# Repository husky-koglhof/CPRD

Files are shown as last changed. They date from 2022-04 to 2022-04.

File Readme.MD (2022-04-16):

# Cardio pulmonary resuscitation Dummy (CPRD)

## CPRD ist eine Simulations Hard- bzw. Software welche dafür eingesetzt werden kann um folgende Themen zu simulieren

- Blutkreislauf
  Es kann ein Relais für einen konfigurierbaren Zeitraum ein- bzw. ausgeschaltet werden.
- Beatmung
  Es kann ein Relais für einen konfigurierbaren Zeitraum ein- bzw. ausgeschaltet werden.
- Temperatur
  Es kann ein Relais für einen konfigurierbaren Zeitraum eingeschaltet werden.
- Puls
  Der angeschlossene Servo kann so konfiguriert werden, um einen Puls nachzuahmen.
- ✨Magic ✨

## Merkmale

Die globalen Parameter werden hier kurz beschrieben:

* Die WLAN SSID ist ```CPRD```
* Das Standard WLAN Passwort ist ```CPRD_password```
* Settings Authentifizierung
  Benutzer: ```admin```
  Passwort: ```admin```
* Update (OTA) Authentifizierung
  Benutzer: ```admin```
  Passwort: ```tobedefined```
* Buttons

  * Speichern -> Speichern der Parameter im EEPROM
  * Start -> Starte mit den aktuell sichtbaren Parametern
  * Abbrechen -> Veränderungen rückgängig machen (nur solange nicht gespeichert wurde)
* Parameter (x)

  * Jeglicher Parameter kann mittels dem Schieberegler konfiguriert werden. Der aktuelle Wert wird im Text angezeigt.

##### Blutkreislauf

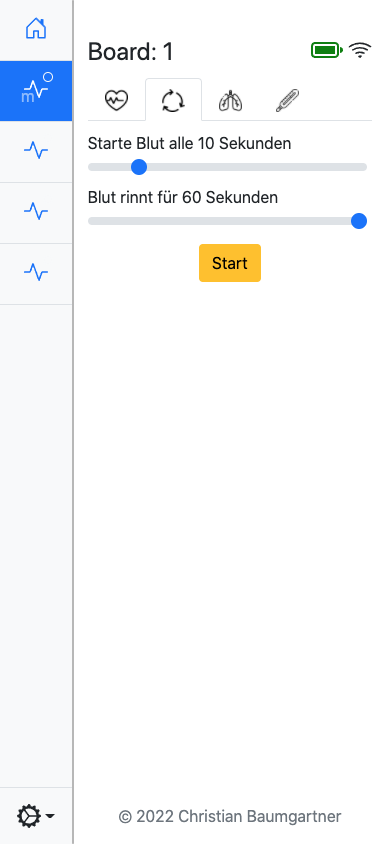
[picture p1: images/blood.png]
Blood


* Starte Blut alle x Sekunden
* Blut rinnt für x Sekunden

##### Beatmung (Lunge)

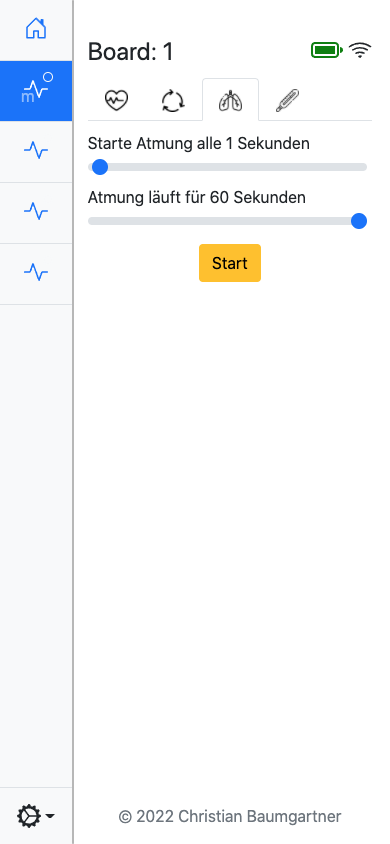
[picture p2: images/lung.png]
Lung


* Starte Atmung alle x Sekunden
* Atmung läuft für x Sekunden

##### Körpertemperatur (Fieber)

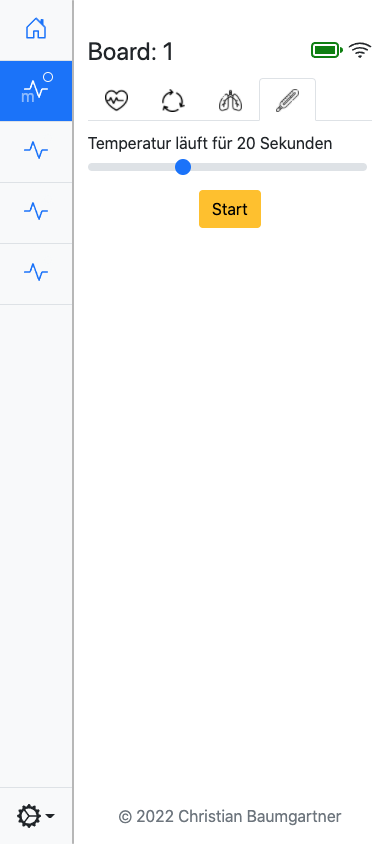
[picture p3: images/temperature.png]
Temperature


* Temperatur läuft für x Sekunden

## Anzeigen

### Zuhause (Home)

Die Hauptansicht zeigt immer alle derzeit verwendeten Boards an.Das derzeit aktive "Master Board" ist zusätzlich mit einem "m" markiert.Sollte ein Board einen zu geringen Batteriestatus haben, wird dies am jeweiligen Board im Menü angezeigt.

* Batterie < 90% = GELB
* Batterie < 80% = ROT

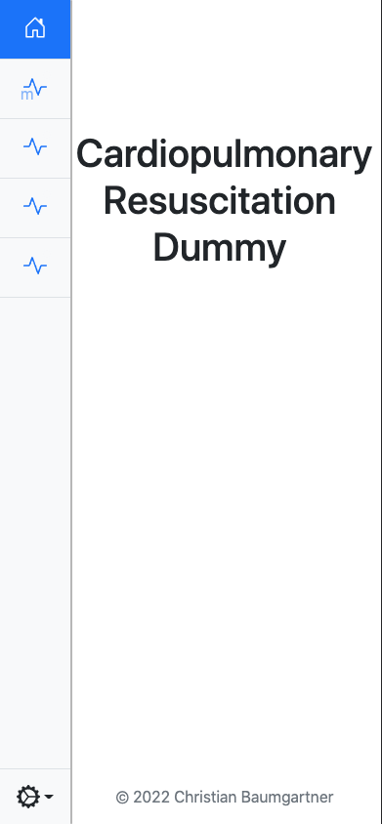
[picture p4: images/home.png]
Home


Sollten Boards nicht mehr aktiv sein (z.B. ausser Reichweite, Batterie leer), werden diese
im linken Baum als "ausgegraut" dargestellt:

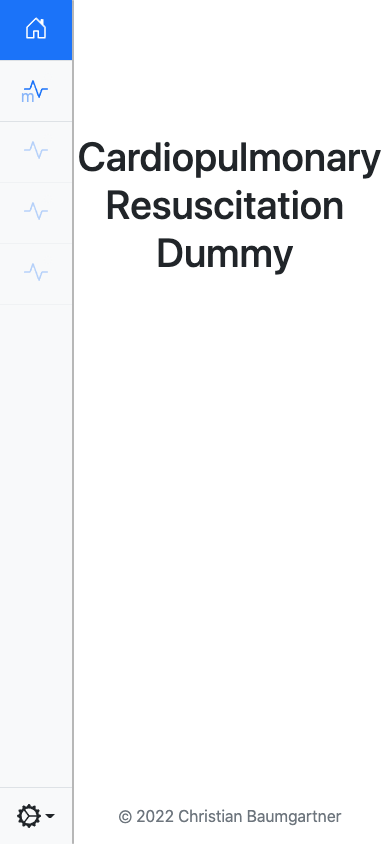
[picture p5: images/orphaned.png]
Orphaned


### Menü

Über das Menü links unten können folgende Seiten geöffnet werden. Dies funktioniert nur bei ausgewähltem Board, da diese Seiten Echtzeitdaten darstellen.

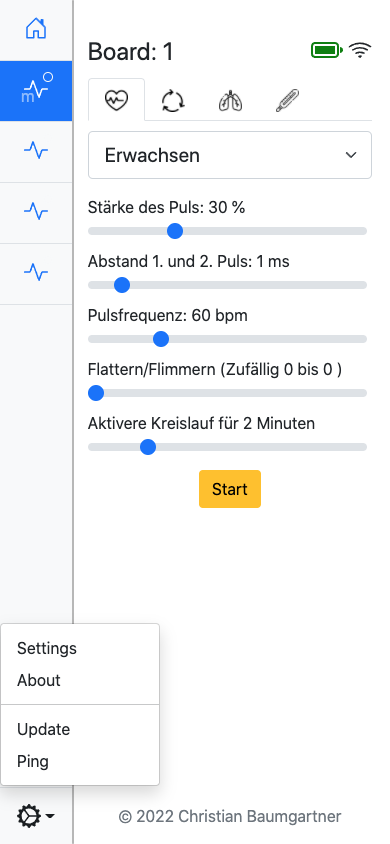
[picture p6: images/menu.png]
Menu


##### Settings

In dieser Seite können folgende Parameter konfiguriert werden:

* Board ID
  Diese sollte nur verändert werden, wenn es zu einem Konflikt mit einem anderen Board kommt, welche die gleiche ID verwendet.
* SSID
  Es ist möglich eine eigene WLAN SSID zu vergeben, z.B. um mehrere "Master" gleichzeitig verwenden zu können.

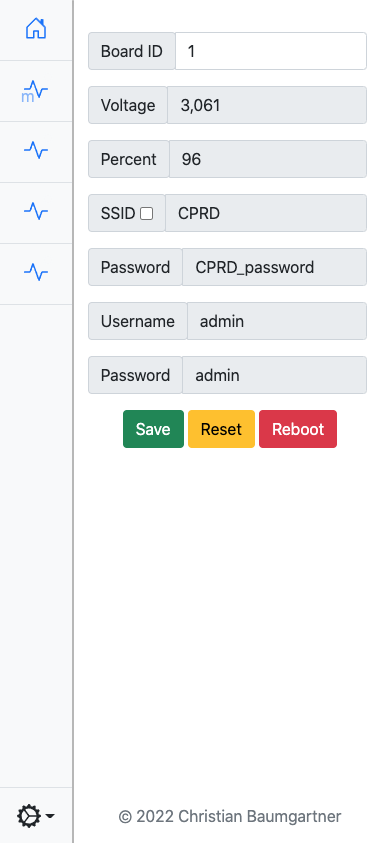
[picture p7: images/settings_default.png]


* Save
  Speichern der Daten im EEPROM
* Reset
  Zurückstellen aller Einstellungen auf den Auslieferungszustand (Board wird neu gestartet)
* Reboot
  Board wird neu gestartet

##### About

Anzeige der aktuellen Versionen bzw. der zusätzlich verwendeten Software.

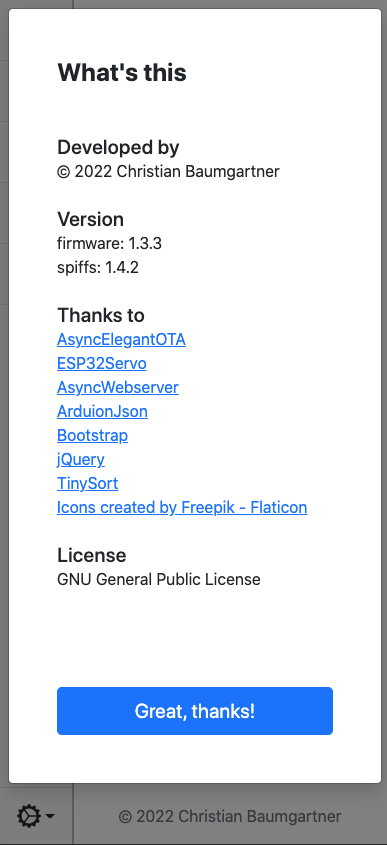
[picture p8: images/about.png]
About


##### Update

Um ein Board aktualisieren zu können, muss es zwingend als "Master" Board aktiv sein. Für die Aktualisierung der Software wird die Auswahl

```Firmware``` und ```firmware.bin``` verwendet.

Für die Aktualisierung der Oberfläche (Webseiten) wird

```Filesystem``` und ```spiffs.bin``` verwendet.

![Update](images/ota.png)

##### Ping

Das derzeit gewählte Board fängt mittels der blauen LED zu blinken an. Somit können die einzelnen Boards aufgefunden werden.

## Anschlüsse

Das System besitzt folgende Anschlüsse (derzeit aktiviert/programmiert):

* USB LadenHierfür kann ein handelsübliches USB Ladegerät verwendet werden.Es darf ausschliesslich nur im abgeschalteten Zustand geladen werden.
  Die LED Anzeige besitzt zwei Zustände
  * Rot: Batterie wird geladen
  * Blau: Batterie ist geladen
* Atmung
  5 Volt Ausgang +/-
* Pumpe
  5 Volt Ausgang +/-
* Temperatur
  5 Volt Ausgang +/-
* Batterie
  Es darf ausschliesslich mit 1S LiPo bzw. 1S LiIon Batterien (z.B. 18650) gearbeitet werden.
  Wenn das Board nicht genutzt wird, sollte die Batterie abgesteckt werden.
* Schalter
  Das Board sollte im nicht genutzten Zustand immer ausgeschaltet sein.

![Pinout](images/board.png)

* Folgende Pins sind derzeit schon auf dem Board vorhanden aber noch nicht aktiv im Einsatz:
  * Relais 4 (Frei)
  * 5 Volt (+/-)
  * 3 Volt (+/-)
  * MISO, MOSI, SS, SCK (z.B. um eine SD Karte anzuschliessen)
  * SDA, SCL (z.B. für externe Sensoren [Temperatur, Luftfeuchte])
  * GPIO1 (TXD)
  * GPIO3 (RXD)

## Development

Die Programmierung erfolgt mittels Visual Studio Code und PlatformIO.

```sh
todo
```

#### Python Webserver

```bash
cd data
gzip -d *.gz
ln -s settings.htm settings
ln -s iframe.htm node
ln -s home.htm home
ln -s config.json update
python3 -m http.server 80
```

#### Bin Dateien erzeugen (OTA Update)

```bash
# spiffs.bin | Filesystem
gzip -9 data/*.js; gzip -9 data/*.css
$HOME/.platformio/penv/bin/platformio run --target buildfs --environment esp32dev
# firmware.bin | Firmware
$HOME/.platformio/penv/bin/platformio run
```

Beim hochladen der spiffs.bin wird die ggf. selbst erzeugte config_new.json entfernt.
Um diese abzuspeichern muss diese (derzeit noch), manuell heruntergeladen werden und die Parameter nach der Aktualisierung per Hand wieder eingestellt werden.
Siehe hierzu [Issue 6](https://github.com/husky-koglhof/CPRD/issues/6)

## Eastereggs

Es sind 3 versteckte Funktionen vorhanden, findest Du sie? 👀️

## Issues

Siehe [Issues](https://github.com/husky-koglhof/CPRD/issues)

## Internals

Für die Kommunikation zwischen den Boards wird [ESP-Now](https://www.espressif.com/en/products/software/esp-now/overview) verwendet.

Beim Start eines Boards wird geprüft ob die SSID (EEPROM) bereits vorhanden ist.

* Wenn ja, wird das Board an diese SSID als Client verbunden
* Wenn nein, wird ein AccessPoint (AP) mit dieser SSID gestartet

Sollte das "Master" Board nicht mehr verfügbar sein (z.B. Stromausfall), kann durch neustart eines beliebigen Boards ein neuer "Master" definiert werden. Die anderen Boards verbinden sich automatisch an diesen als "Client".

Im EEPROM (Adresse 1) sind folgende Daten abgelegt:

```
typedef struct eeprom_struct {
    int boardID;
    bool enableSSID;
    String ssid;
} eeprom_struct;
```

Die Standard Konfiguration liegt unter [/data/config.json](/data/config.json).
Beim verändern und speichern von neuen Daten wird unter ```/data``` eine neue Datei ```config_new.json``` mit den veränderten Daten abgelegt.

Wird über die Settings Seite ein Reset durchgeführt, wird der EEPROM auf den Standard zurückgesetzt und die Datei ```config_new.json``` entfernt.

##### Partitions

Die Partitionstabelle sieht folgendes vor

[Online Editor](https://docs.google.com/spreadsheets/d/1AGFspAP9vPB_HL5ffOyhbxU-URNjrqpOha71I5A4MEI/edit#gid=0)

```bash
# ESP-IDF Partition Table
# Name, Type, SubType, Offset, Size, Flags
nvs,data,nvs,0x9000,20K,
otadata,data,ota,0xe000,8K,
app0,app,ota_0,0x10000,1280K,
app1,app,ota_1,0x150000,1280K,
spiffs0,data,spiffs,0x290000,72K,
spiffs1,data,spiffs,0x2a2000,1400K,
```

```bash
# read out old partition table
python3 $HOME/.platformio/packages/framework-espidf@3.40300.0/components/esptool_py/esptool/esptool.py -p /dev/cu.SLAB_USBtoUART read_flash 0x8000 0xc00 ptable.img
# partition to csv
python3 $HOME/.platformio/packages/framework-espidf/components/partition_table/gen_esp32part.py ptable.img
# erase filesystem
$HOME/.platformio/penv/bin/platformio run --target erase --environment esp32dev
# write new firmware
$HOME/.platformio/penv/bin/platformio run --target upload
# write new filesystem
$HOME/.platformio/penv/bin/platformio run --target uploadfs --environment esp32dev
#
# create firmware incl. partitions.csv
$HOME/.platformio/penv/bin/platformio run
# create filesystem
$HOME/.platformio/penv/bin/platformio run --target buildfs --environment esp32dev
#
# monitor
$HOME/.platformio/penv/bin/platformio device monitor
```

## License

GPL v2

**Free Software, Hell Yeah!**

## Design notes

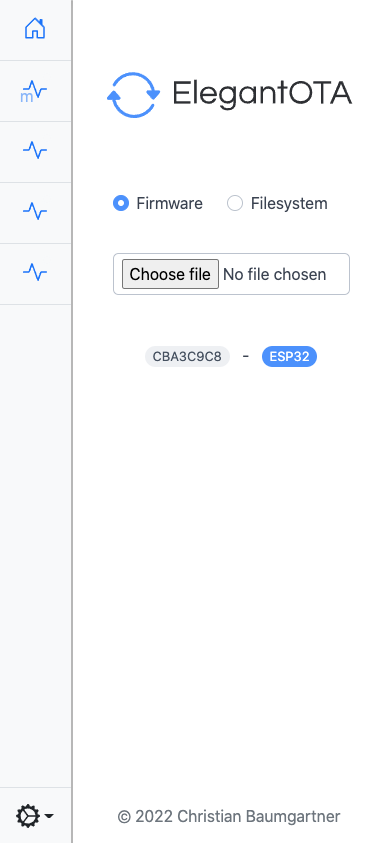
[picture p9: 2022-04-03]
images/ota.png

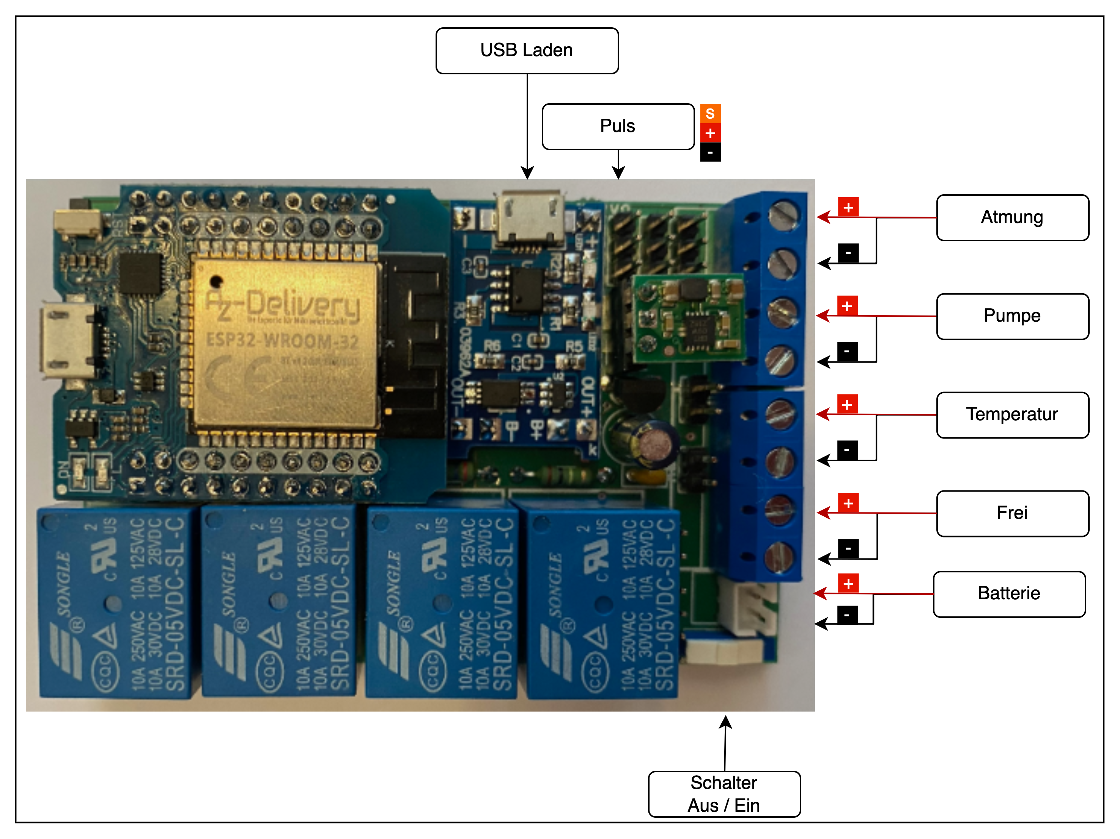
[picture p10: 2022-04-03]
images/board.png

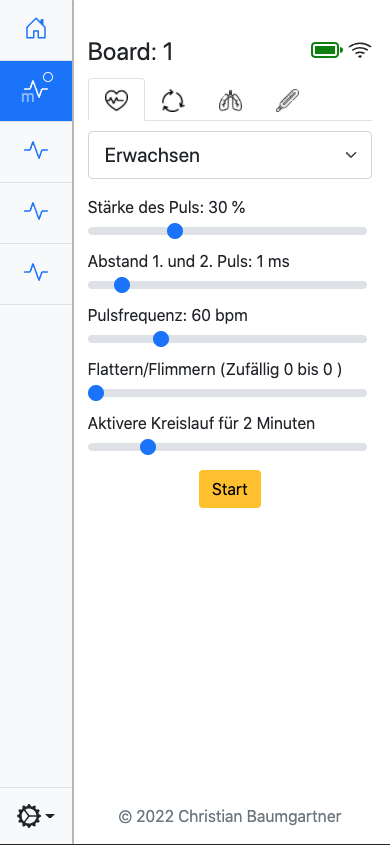
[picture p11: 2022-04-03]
images/pulse.png

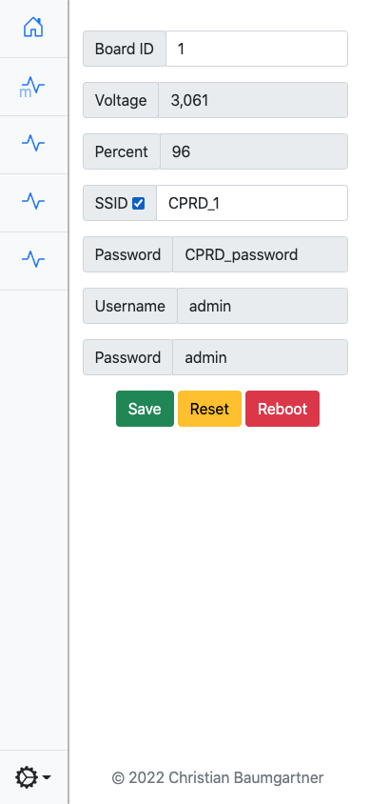
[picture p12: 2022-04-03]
images/settings.png

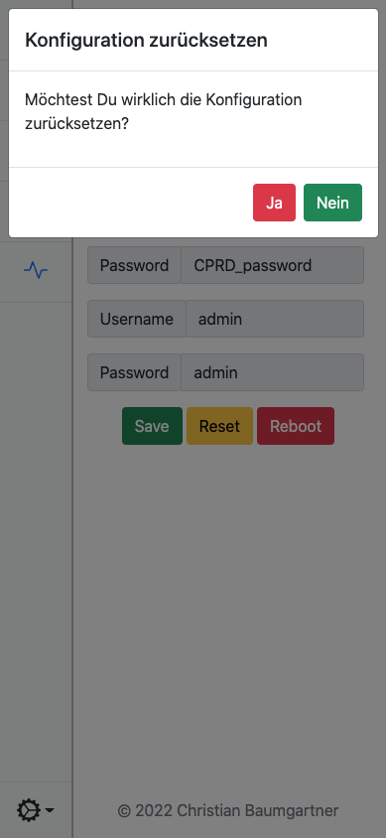
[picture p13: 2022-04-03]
images/reset.png

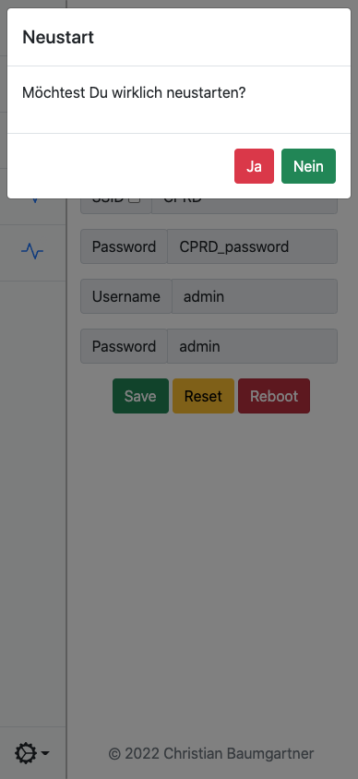
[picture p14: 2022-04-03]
images/reboot.png

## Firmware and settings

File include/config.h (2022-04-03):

#ifndef Config_h
#define Config_h
#include <Arduino.h>

#define FIRMWARE_VERSION    "1.3.3"
#define SPIFFS_VERSION      "1.4.2"

#define _SCK    SCK     // 18   SPI BUS
#define _SS     SS      // 5    SPI BUS
#define _MOSI   MOSI    // 23   SPI BUS
#define _MISO   MISO    // 19   SPI BUS

#define LED   T2

#define GPIO1 TX   // TXD
#define GPIO2 RX   // RXD

#define RELAY1 A17 // IO27
#define RELAY2 A4  // IO32
#define RELAY3 A10 // IO4
#define RELAY4 17  // IO17

#define SERVO A5   // IO33

#define PWR   A0

#define DEFAULT_SSID            "CPRD"
#define DEFAULT_SSID_PASS       "CPRD_password"
#define DEFAULT_CHANNEL         1

#define DEFAULT_HTTP_USER   "admin"
#define DEFAULT_HTTP_PASS   "admin"

#define ROOT_USER   "admin"
#define ROOT_PASS   "tobedefined"

#endif

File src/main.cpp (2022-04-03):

#include <CPRD.h>
#include <config.h>
#include <WiFi.h>

/* BROWNOUT DETECTION DISABLED */
#include "soc/soc.h"
#include "soc/rtc_cntl_reg.h"
/* BROWNOUT DETECTION DISABLED */

/* TIMERS */
static const uint8_t TFc_MaxNumOfTimers = 20;

static uint8_t TFv_NoOfRegisteredTimers = 0;
static uint8_t TFv_TimerIDNr[TFc_MaxNumOfTimers + 1];
static uint32_t TFv_TimeStampMillis[TFc_MaxNumOfTimers + 1];

void TF_ClearAllTimers() {
    TFv_NoOfRegisteredTimers = 0; 
}

int TF_OccupyTimer() {
    int l_Result = -1;
    if (TFv_NoOfRegisteredTimers < TFc_MaxNumOfTimers) {
        TFv_NoOfRegisteredTimers = TFv_NoOfRegisteredTimers + 1;
        l_Result = TFv_NoOfRegisteredTimers;
    } else {
        l_Result = -1;
    }
    return l_Result;   
}

int TF_StartTimer(int8_t p_TimerID_Nr) {
    int l_result = -1;

    if ((p_TimerID_Nr  >0) && (p_TimerID_Nr  <= TFc_MaxNumOfTimers)) {
        TFv_TimeStampMillis[p_TimerID_Nr] = millis();
        l_result = 0;
    } else {
        l_result = -1;
    }
    return l_result;
}

int TF_UpDateTimer(int8_t p_TimerID_Nr, uint32_t p_IntervalMillis) {
    int l_result = -1;
    if ((p_TimerID_Nr  > 0) && (p_TimerID_Nr  <= TFc_MaxNumOfTimers)) {
        TFv_TimeStampMillis[p_TimerID_Nr] = TFv_TimeStampMillis[p_TimerID_Nr] + p_IntervalMillis;
        l_result = 0;
    }
    return l_result;  
}


uint32_t TF_elapsedTime(int8_t p_TimerID_Nr) {
    uint32_t l_result = -1;
    if ((p_TimerID_Nr > 0 ) && (p_TimerID_Nr  <= TFc_MaxNumOfTimers)) {
        l_result = TFv_TimeStampMillis[p_TimerID_Nr] - millis();
    }
    return l_result; 
}

int SendDataTimer;
/* TIMERS */
CPRD* cprd;

bool searchForHotSpot() {
    /* Check if there already exists a hotspot */
    if (int32_t n = WiFi.scanNetworks()) {
        Serial.print("Found ");Serial.print(n);Serial.println(" Networks");
        String ssid = DEFAULT_SSID;
        eeprom_struct eepromObj = cprd->getEEPROM();
        if (eepromObj.enableSSID) {
            ssid = eepromObj.ssid;
        }
        Serial.print("Searching for '");Serial.print(ssid);Serial.println("'");
        for (uint8_t i=0; i<n; i++) {
            Serial.print("--> ");Serial.println(WiFi.SSID(i));
            if (!strcmp(ssid.c_str(), WiFi.SSID(i).c_str())) {
                return true;
            }
        }
    }
    return false;
}

void setup() {
    Serial.begin(115200);
    Serial.setDebugOutput(true);

    TF_ClearAllTimers(); 

    // prepare non-blocking timer for use
    SendDataTimer = TF_OccupyTimer();
    if (SendDataTimer > 0) {
        TF_StartTimer(SendDataTimer);
    } else {
        Serial.println("registering Timer was NOT successful!");
    }

    /* BROWNOUT DETECTION DISABLED */
    WRITE_PERI_REG(RTC_CNTL_BROWN_OUT_REG, 0);
    /* BROWNOUT DETECTION DISABLED */

    cprd = new CPRD();
    // initialize digital pin LED_BUILTIN as an output.
    pinMode(LED, OUTPUT);
    digitalWrite(LED, LOW);

    if (searchForHotSpot()) {
        // CLIENT MODE
        cprd->setClient(true);
    } else {
        // SERVER MODE
        cprd->setClient(false);
        digitalWrite(T2, HIGH);
    }
    cprd->initialize();
    if (cprd->isClient()) {
        cprd->ScanForSlave();
    }
}

void loop() {
  if (TF_elapsedTime(SendDataTimer) > 2000) { // set to 2 seconds so you have time to read the serial output
     TF_UpDateTimer(SendDataTimer,2000);      // if you make it faster you won't be able to read the whol emessage
     cprd->loop();
    }
}

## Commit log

2022-04-03 Update Readme.MD, board.png Hintergrund
2022-04-03 Update Readme.MD, use source files, upload fritzing board
    [Puppe5.fzz]
2022-04-05 Issue 6 fixed
    [partitions.csv]
